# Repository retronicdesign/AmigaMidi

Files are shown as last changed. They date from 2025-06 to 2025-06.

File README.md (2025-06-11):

# Amiga Serial Midi Adapter V1.3


## Schematic

(C)2025 Retronic Design - Open Hardware

## Features
- This serial midi interface is compatible with most Amiga Midi softwares.
- It simply convert serial RS-232 RX and TX signals to MIDI TTL standard.
- MIDI IN is opto-isolated to prevent ground loops and induction noise.
- Self powered via serial port.
- Convenient thru connector to connect other instruments to MIDI IN in daisy-chain.
- Tested on Bar and Pipes professional and OCTA-MED. (Let us know yours!)

## Versions
- v1.0 Initial release
- v1.1 Corrected LED polarity
- v1.2 Corrected DB-25 PCB footprint
- v1.3 Corrected Schematic and PCB (Larger traces / LED alignement / Smaller but capable 5v regulator)

## PCB



## Pictures

*Please note that this picture is an outdated version 1.0 of the serial Midi adapter.

You can have it build at [PCBWay](https://pcbway.com/g/J4X1Dw) under my shared projects.

## Part List

| Quantity | Designator | Part |
| --- | --- | --- |
| 1 |	C1|	100pF |
| 6 |	C2,C3,C4,C5,C6,C7|	0.1uF |
| 1 |	D1 | 1N4148 |
| 2 |	D2,D3 | LED |
| 3 |	J1,J2,J3 | DIN 5 FEMALE |
| 1 |	J4 | D-SUB 25 Female |
| 5 |	R1,R2,R3,R4,R5 | 220 Ohms |
| 2 |	R6,R8 | 1K |
| 1 |	R7 | 3.3K |
| 1 |	U1 | 6N136 |
| 1 |	U2 | MAX232 |
| 1 |	U3 | L4931-5.0 |

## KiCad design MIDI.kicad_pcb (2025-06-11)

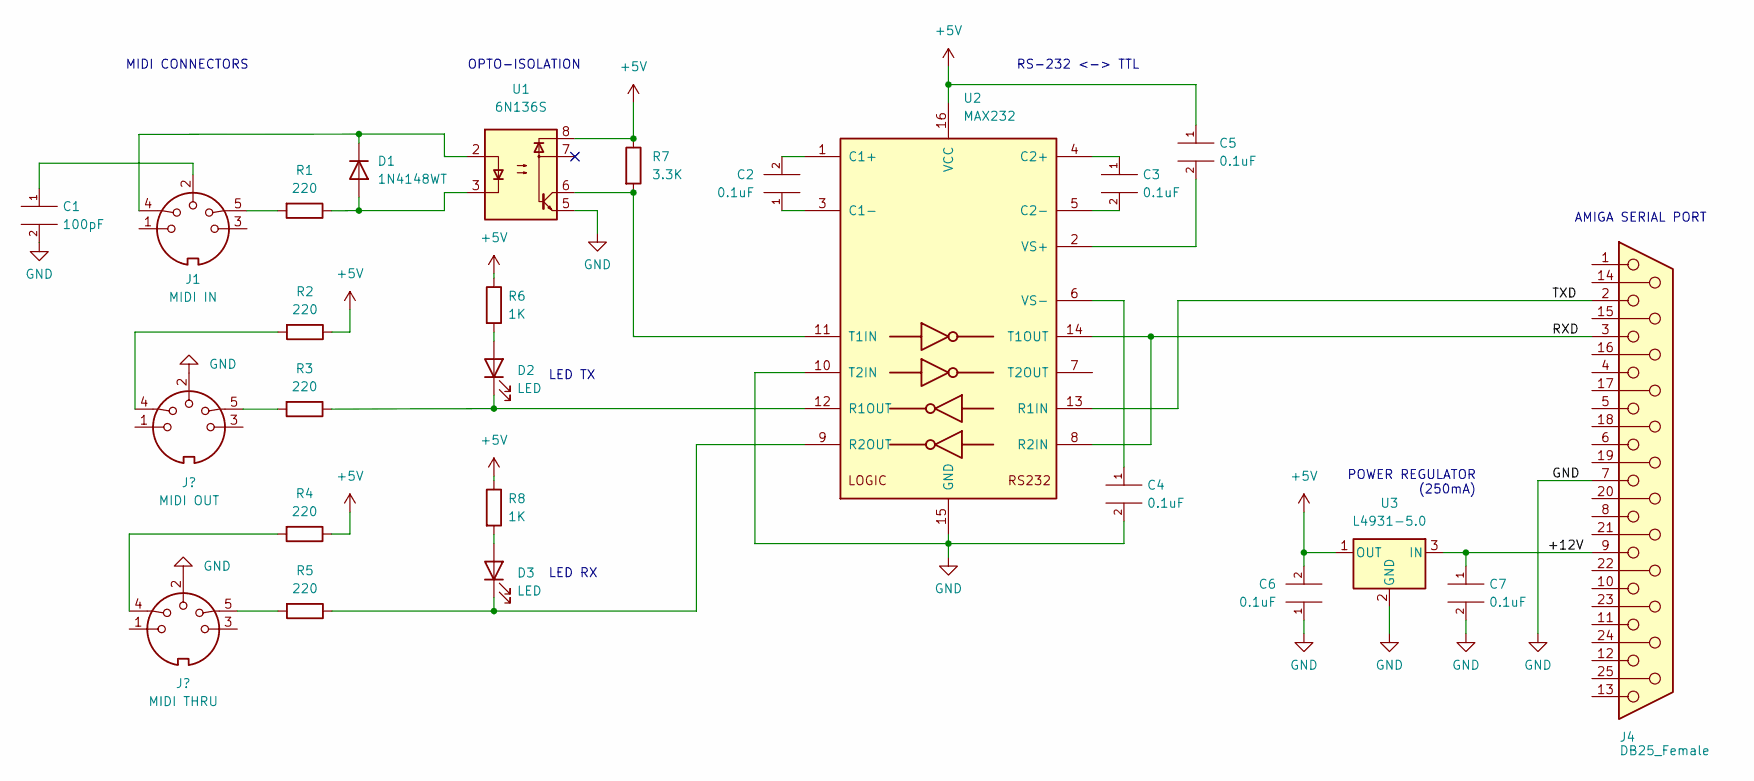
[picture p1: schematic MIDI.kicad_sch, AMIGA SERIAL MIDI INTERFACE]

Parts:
C1: 100pF; C_Disc_D3.0mm_W1.6mm_P2.50mm
C2, C3, C4, C5, C6, C7: 0.1uF; C_Disc_D3.0mm_W1.6mm_P2.50mm
D1: 1N4148WT; D_A-405_P7.62mm_Horizontal
D2, D3: LED; LED_D3.0mm
J1: MIDI IN; MIDI_DIN5
J4: DB25_Female; DSUB-25_Female_Horizontal_P2.77x2.84mm_EdgePinOffset7.70mm_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
R1, R2, R3, R4, R5: 220; R_Axial_DIN0204_L3.6mm_D1.6mm_P7.62mm_Horizontal
R6, R8: 1K; R_Axial_DIN0204_L3.6mm_D1.6mm_P7.62mm_Horizontal
R7: 3.3K; R_Axial_DIN0204_L3.6mm_D1.6mm_P7.62mm_Horizontal
U1: 6N136S; DIP-8_W7.62mm_Socket
U2: MAX232; DIP-16_W7.62mm
U3: L4931-5.0; TO-92L_Inline

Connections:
+5V: C5.1, C6.2, R2.1, R4.1, R6.1, R7.1, R8.1, U1.8, U2.16 (VCC), U3.1 (OUT)
/+12V: C7.1, J4.9, U3.3 (IN)
/RXD: J4.3, U2.8 (R2IN), U2.14 (T1OUT)
/TXD: J4.2, U2.13 (R1IN)
GND: C1.2, C4.2, C6.1, C7.2, J4.0, J4.7, U1.5, U2.10 (T2IN), U2.15 (GND), U3.2 (GND); also elsewhere on the board
unnamed: C1.1, J1.2
unnamed: C2.1, U2.3 (C1-)
unnamed: C2.2, U2.1 (C1+)
unnamed: C3.1, U2.4 (C2+)
unnamed: C3.2, U2.5 (C2-)
unnamed: C4.1, U2.6 (VS-)
unnamed: C5.2, U2.2 (VS+)
unnamed: D1.1 (K), J1.4, U1.2
unnamed: D1.2 (A), R1.1, U1.3
unnamed: D2.1 (K), R3.1, U2.12 (R1OUT)
unnamed: D2.2 (A), R6.2
unnamed: D3.1 (K), R5.1, U2.9 (R2OUT)
unnamed: D3.2 (A), R8.2
unnamed: J1.5, R1.2
unnamed 19: R2.2; also elsewhere on the board
unnamed 20: R3.2; also elsewhere on the board
unnamed 21: R4.2; also elsewhere on the board
unnamed 22: R5.2; also elsewhere on the board
unnamed: R7.2, U1.6, U2.11 (T1IN)

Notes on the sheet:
AMIGA SERIAL PORT
MIDI CONNECTORS
LED TX
LED RX
RS-232 <-> TTL
OPTO-ISOLATION
POWER REGULATOR (250mA)

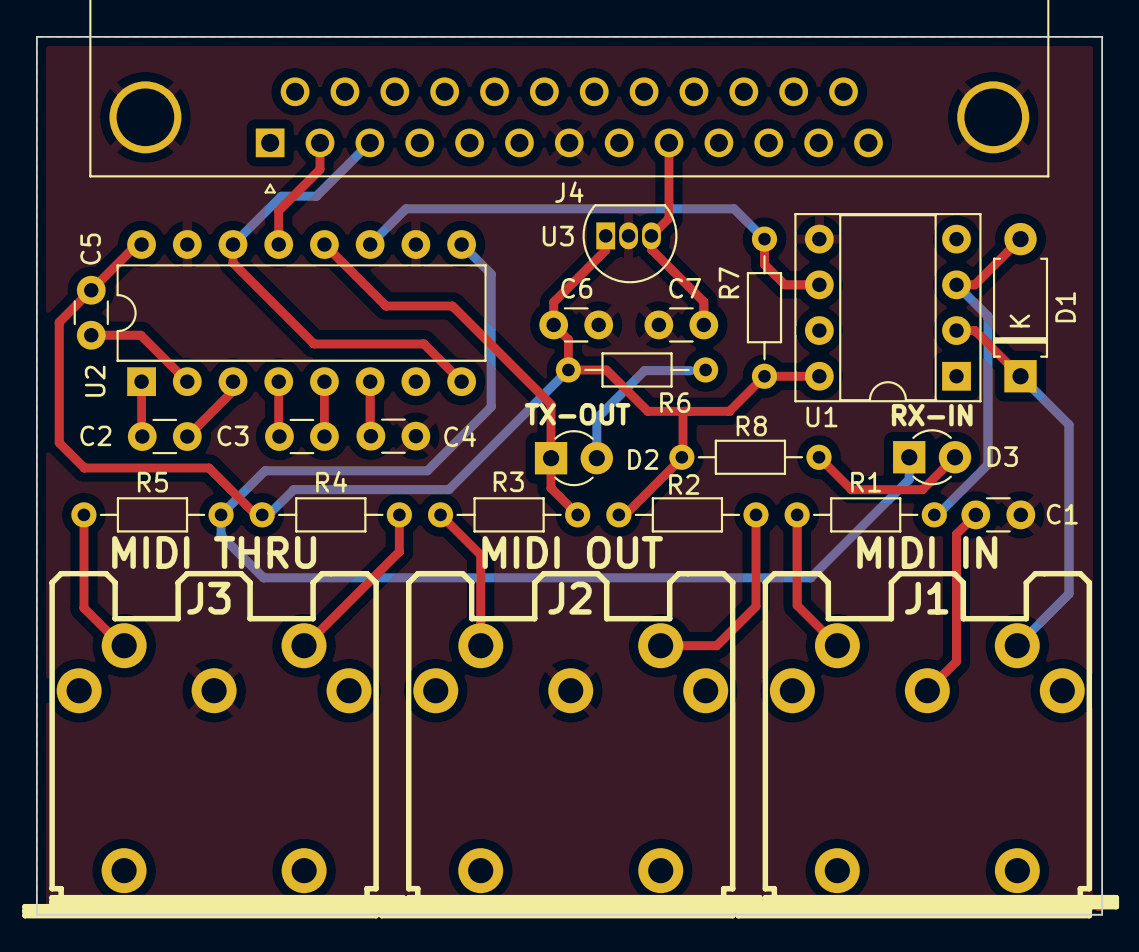
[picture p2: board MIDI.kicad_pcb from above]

Board: 2 copper layers, 59.2 x 48.8 mm, 25 parts (0 on the bottom side), 24 nets.

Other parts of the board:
J2: MIDI OUT; MIDI_DIN5
J3: MIDI THRU; MIDI_DIN5

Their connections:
GND: J2.2, J3.2; also elsewhere on the board
unnamed 19: J2.4; also elsewhere on the board
unnamed 20: J2.5; also elsewhere on the board
unnamed 21: J3.4; also elsewhere on the board
unnamed 22: J3.5; also elsewhere on the board

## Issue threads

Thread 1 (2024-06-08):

PC support?

paulguy, 2024-06-08:
This isn't really an issue but more of a question (though maybe this could be a feature request).

Would this work on a PC through a 9 to 25 pin adapter with something like softmpu?  I'm trying to get MIDI on a DOS PC laptop which has no MIDI capability, and this seems like the most reasonable option available for this, assuming it'd be compatible.
I've found a couple other options which I haven't been able to find designs available for and which are also out of stock that are more directly intended for DOS PCs/softmpu.  This one having an open design that can be built seems to be the only option available at this point that is close to what I'd like.

paulguy, 2024-06-10:
I was considering serial to MIDI adapters since the laptop i'm trying to use (a pocket386) doesn't have any sort of MIDI or a gameport or anything like that at all, but does have serial.
I was imagining though yeah that power would be an issue.  I didn't know if the power was just an Amiga thing.

retronicdesign, 2024-06-11:
Midi is 31250 bauds. Check if it can get up to that speed.

Power is not on a DB9 for sure.

Francis Gradel, B.Eng.

 ***@***.***> ***@***.***

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
